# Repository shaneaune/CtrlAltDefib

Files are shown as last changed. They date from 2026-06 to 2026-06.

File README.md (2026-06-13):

# Ctrl+Alt+Defib

**Ctrl+Alt+Defib** is an ESP32-based power outage monitoring and automated shutdown system designed for Proxmox servers.

The system monitors utility power using a standard 5V USB power adapter. When utility power is lost, a configurable shutdown timer begins. If power is not restored before the timer expires, the Ctrl+Alt+Defib unit sends a secure shutdown request to a Proxmox shutdown service running in a lightweight Linux container. The shutdown service then performs a controlled shutdown of the Proxmox host to protect virtual machines, containers, and storage from unexpected power loss before the UPS batteries are depleted.

The ESP32 remains powered by the UPS during an outage, allowing it to continue monitoring power status. When utility power is restored, a separate configurable startup timer begins. Once the startup delay has expired, the Ctrl+Alt+Defib unit automatically sends a Wake-on-LAN packet to restart the Proxmox host.

The project is designed to be simple to deploy, inexpensive to build, and easy to configure. All settings are managed through a built-in web interface hosted directly on the Ctrl+Alt+Defib unit.

---

## Features

* Configurable shutdown delay timer
* Web-based configuration interface
* Secure token-protected shutdown requests
* Automated Proxmox shutdown-service container installer
* Wake-on-LAN support for automatic Proxmox host startup after power restoration
* Local event logging and status monitoring
* Open-source hardware and firmware
* Designed and tested for the ESP32-ETH02 Ethernet module

---

## Repository Structure

```text
.
├── docs
│   └── images
│       ├── Arduino-IDE-Settings.jpg
│       ├── Case-End.jpg
│       ├── Case-esp32.jpg
│       ├── Case-inside.jpg
│       ├── Hat-schematic.png
│       ├── Hookup-Diagram.png
│       ├── PCB-hat.jpg
│       ├── Webpage-config.jpg
│       ├── Webpage-log.jpg
│       └── Webpage-status.jpg
├── enclosure
│   └── stl
│       ├── CtrlAltDefib Case Lid.stl
│       ├── CtrlAltDefib Case.stl
│       └── Printing-Notes.md
├── firmware
│   └── CtrlAltDefib
│       └── CtrlAltDefib.ino
├── hardware
│   └── CtrlAltDefib-HAT
│       ├── CtrlAltDefib-HAT-Gerbers.zip
│       ├── CtrlAltDefib-HAT-Schematic.pdf
│       └── README.md
├── LICENSE
├── README.md
└── shutdown-service
    └── install-shutdown-service.sh
```

---

## How It Works

1. The Ctrl+Alt+Defib unit is powered by the UPS so it remains operational during a power outage.
2. A standard 5V USB-C power adapter monitors the presence of utility power.
3. If utility power is lost, a configurable shutdown countdown begins.
4. If utility power returns before the timer expires, the shutdown countdown is cancelled.
5. If the timer expires, the Ctrl+Alt+Defib unit sends a secure shutdown request to the Proxmox shutdown service.
6. The shutdown service cleanly shuts down the Proxmox host.
7. When utility power is restored, a configurable startup countdown begins.
8. When the startup countdown expires, the Ctrl+Alt+Defib unit automatically sends a Wake-on-LAN packet to restart the Proxmox host.

<p align="center">
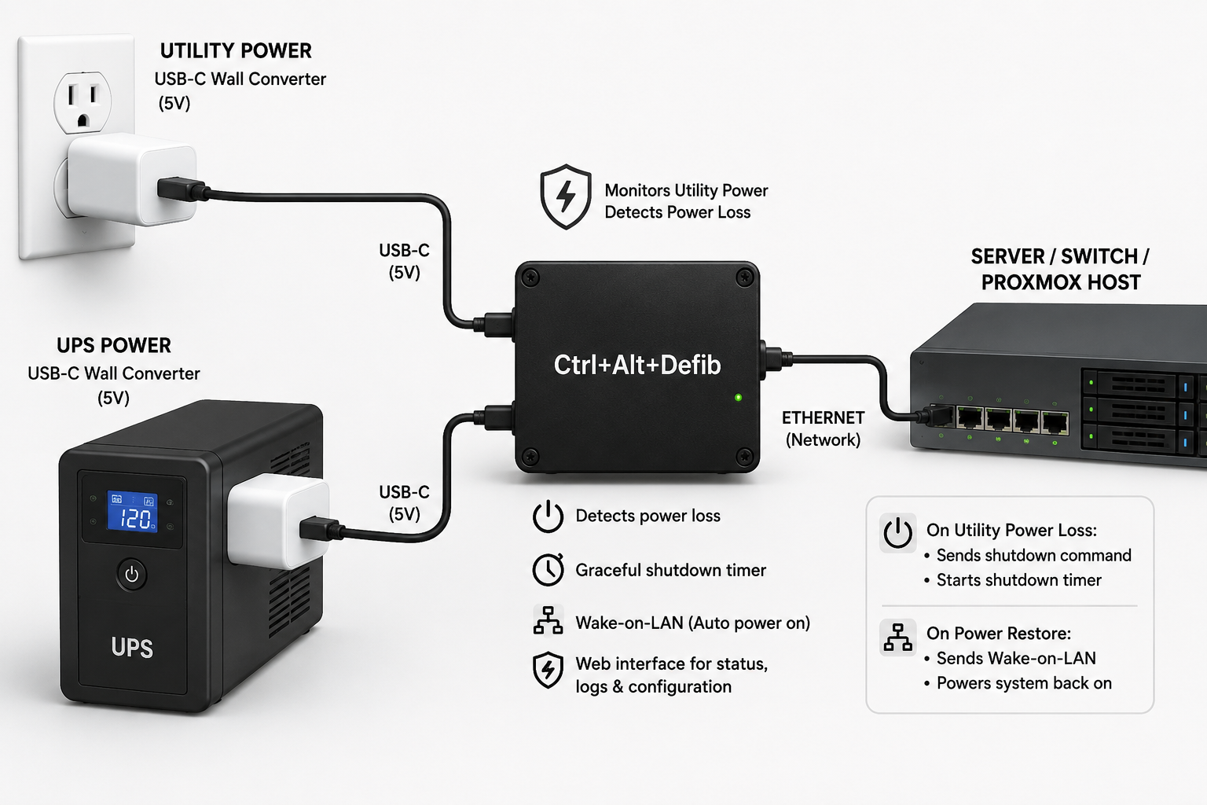
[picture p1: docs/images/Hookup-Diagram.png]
  
</p>

---

## Hardware

All hardware files required to build the project are located in the hardware/CtrlAltDefib-HAT directory.

The utility power sensing adapter must be connected to a non-UPS outlet. If it is connected to a UPS-backed outlet, the system will be unable to detect a utility power failure.

The Ctrl+Alt+Defib unit must remain powered during a utility power outage. This is typically accomplished using a UPS, but a suitable USB battery pack may also be used.

Network connectivity between the Ctrl+Alt+Defib unit and the Proxmox host must remain available during a power outage. If the Ctrl+Alt+Defib unit communicates through a network switch, the switch should also remain powered until the shutdown process is complete.

Failure to maintain power to the Ctrl+Alt+Defib unit or the network path will prevent the shutdown request from reaching the Proxmox host. 

---

## Assembled Unit

<p align="center">
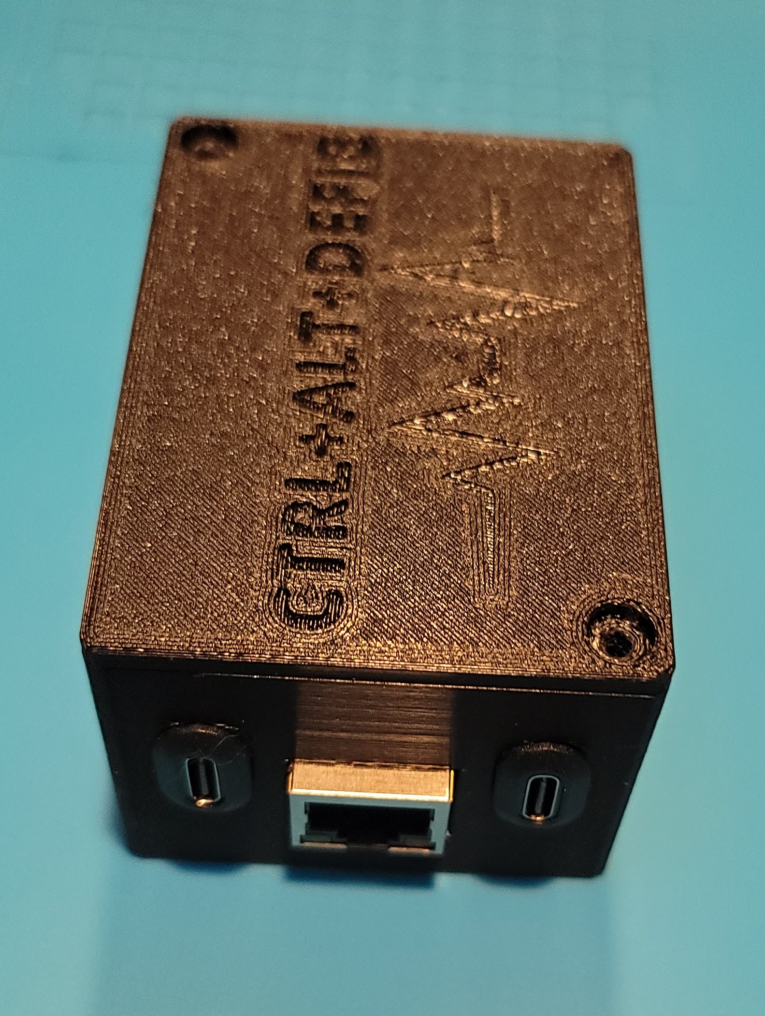
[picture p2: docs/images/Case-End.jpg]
  
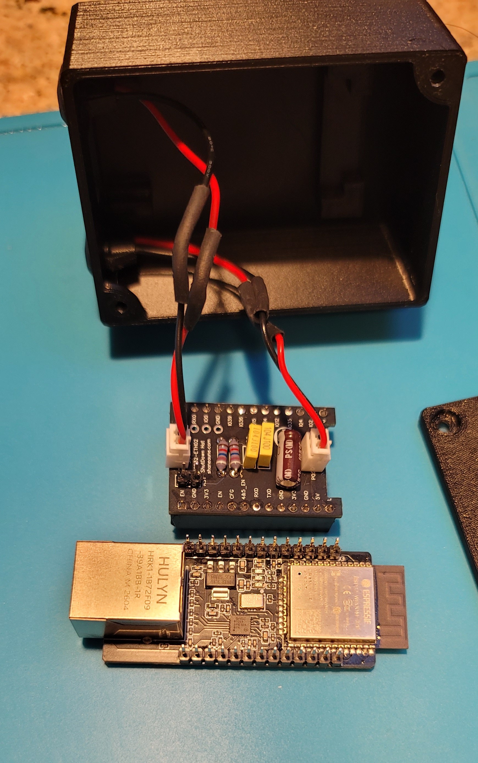
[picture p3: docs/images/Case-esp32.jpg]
  
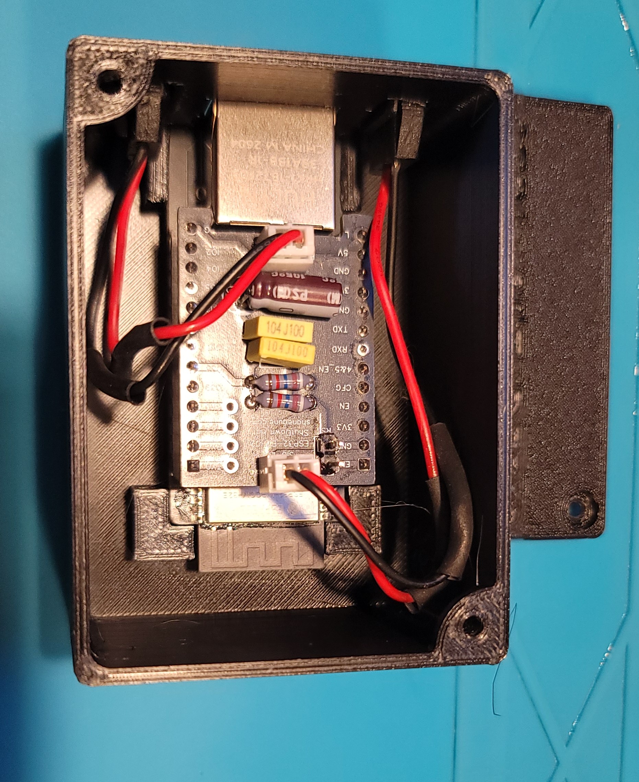
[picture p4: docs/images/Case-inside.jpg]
  
</p>

---

### Included Files

* Bill of Materials (BOM)
* PCB design files
* Schematic files

Refer to the hardware README for the complete bill of materials, sourcing information, and assembly notes.

The 3D printable enclosure files are located in the `enclosure` directory.

### Programming the ESP32-ETH02

The ESP32-ETH02 does not include a built-in USB programming interface.

To upload firmware, you will need one of the following:

* An ESP32-ETH02 programming adapter board
* A USB-to-Serial adapter with access to the required programming pins

The easiest option is to use one of the ESP32-ETH02 programming adapter boards available from Amazon, AliExpress, and other suppliers. These adapter boards typically provide:

* USB-C connection
* USB-to-Serial interface
* BOOT button
* RESET button
* Power regulation

These adapters allow the ESP32-ETH02 to be programmed directly from the Arduino IDE over USB without additional wiring.

---

## Firmware Installation

The firmware has been developed and tested on the ESP32-ETH02 Ethernet module using:

| Component | Version |
|---|---|
| Arduino IDE | 2.3.10 |
| ESP32 Board Package (Espressif Systems) | 3.3.10 |

Other LAN8720-based ESP32 Ethernet boards may work, but they have not been tested with this project and are not currently supported.

Open the `CtrlAltDefib.ino` sketch located in:

```text
firmware/CtrlAltDefib/
```

and upload it to your ESP32-ETH02 using the Arduino IDE.

### Install ESP32 Board Support

Before compiling the firmware, install the ESP32 board package using the Arduino IDE Board Manager.

1. Open **Tools → Board → Boards Manager**.
2. Search for:

ESP32

3. Install the **ESP32** package published by **Espressif Systems**.

The firmware was developed and tested using version **3.3.10** of the ESP32 board package.

After installation, select:

Tools → Board → ESP32 Arduino → ESP32 Dev Module

and configure the settings shown below.

### Arduino IDE Settings

The firmware was developed and tested using the following Arduino IDE settings:

| Setting | Value |
| --- | --- |
| Board | ESP32 Dev Module |
| CPU Frequency | 240MHz (WiFi/BT) |
| Core Debug Level | Info |
| Erase All Flash Before Sketch Upload | Disabled |
| Events Run On | Core 1 |
| Flash Frequency | 40MHz |
| Flash Mode | DIO |
| Flash Size | 4MB (32Mb) |
| JTAG Adapter | Disabled |
| Arduino Runs On | Core 1 |
| Partition Scheme | Default 4MB with spiffs (1.2MB APP/1.5MB SPIFFS) |
| PSRAM | Disabled |
| Upload Speed | 115200 |
| Zigbee Mode | Disabled |

<p align="left">
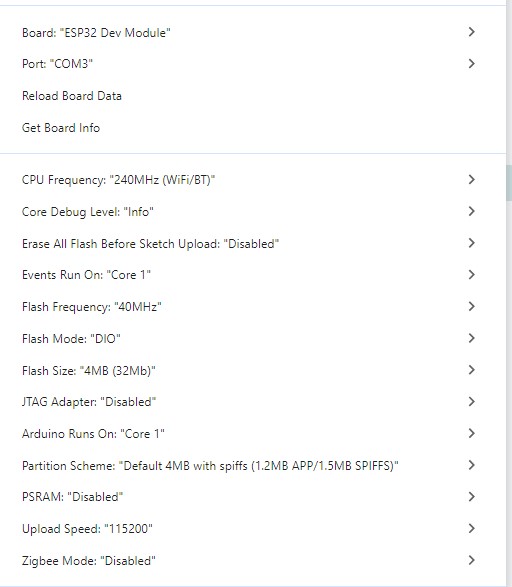
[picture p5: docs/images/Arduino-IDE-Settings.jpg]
  
</p>

---

### Configure Web Interface Credentials

Before compiling and uploading the firmware, edit the following lines in `CtrlAltDefib.ino`:

```cpp
constexpr const char *UI_USERNAME = "admin";
constexpr const char *UI_PASSWORD = "CHANGE-ME";
```

Change the password to a secure value before uploading the firmware.

Example:

```cpp
constexpr const char *UI_USERNAME = "admin";
constexpr const char *UI_PASSWORD = "MySecurePassword";
```

The web interface will use these credentials for authentication.

---

### Uploading the Firmware

1. Connect the ESP32-ETH02 to your programming adapter.
2. Connect the programming adapter to your computer using USB.
3. Open `firmware/CtrlAltDefib/CtrlAltDefib.ino` in the Arduino IDE.
4. Configure the username and password in the sketch before compiling.
5. Select the settings listed above.
6. Compile and upload the firmware.

### Required Libraries

Install any required libraries when prompted by the Arduino IDE.

After the firmware has been uploaded successfully, continue with the Proxmox Shutdown Service Setup section.

---

## Proxmox Shutdown Service Setup

The shutdown service runs inside a lightweight Debian LXC container and receives authenticated shutdown requests from the Ctrl+Alt+Defib unit .

The installer automatically creates and configures the container, installs all required software, generates SSH keys, and configures the shutdown service.

### Prerequisites

* Proxmox VE 8.x or newer
* Internet access from the Proxmox host
* A Debian 12 container template available in Proxmox

If a Debian 12 template is not already installed:

1. Open the Proxmox web interface.
2. Select the local storage.
3. Open **CT Templates**.
4. Download the latest **Debian 12 Standard** template.

### Download the Repository

Log in to the Proxmox host as root and clone the repository:

```bash
git clone https://github.com/shaneaune/CtrlAltDefib.git
cd CtrlAltDefib/shutdown-service
```

### Run the Installer

Make the installer executable and start it:

```bash
chmod +x install-shutdown-service.sh
./install-shutdown-service.sh
```

The installer will:

* Create the shutdown-service container
* Install required packages
* Generate the SSH shutdown key
* Install and start the shutdown service
* Display the Ctrl+Alt+Defib unit configuration settings
* Generate the authorized_keys entry required for Proxmox shutdown access

### Complete the Action Required Step

When the installer completes, it will display a line similar to:

```text
command="shutdown -h now",no-port-forwarding,no-agent-forwarding,no-pty ssh-ed25519 ...
```

Copy the entire line and add it to the Proxmox host's authorized_keys file:

```bash
nano /root/.ssh/authorized_keys
```

Paste the generated line onto a new line at the end of the file.

To save the file:

Ctrl+O
Enter

To exit Nano:

Ctrl+X

On the Proxmox host you can retrieve the generated line again at any time with:

```bash
pct exec <CTID> -- cat /root/proxmox_authorized_key.txt
```

---

### Record the  Ctrl+Alt+Defib Config Settings

The installer will display:

* Shutdown Service IP
* Shutdown Service Port
* Shutdown Token

These values will be required when configuring the Ctrl+Alt+Defib settings in the web interface.

---

## First Shutdown Test Preparation

The first time the shutdown-service container connects to the Proxmox host, SSH will prompt to verify the Proxmox host key.

Before performing the first shutdown test:

1. Open a console to the shutdown-service container.

2. Run:

pct enter <CTID>

3. Leave the console open during the first shutdown test.

When the shutdown timer expires, you will see a message similar to:

The authenticity of host '10.0.0.xxx' can't be established.
ED25519 key fingerprint is SHA256:xxxxxxxxxxxxxxxxxxxxxxxxxxxx.
Are you sure you want to continue connecting (yes/no/[fingerprint])?

Type:

yes

and press Enter.

The Proxmox host key will be saved and all future shutdowns will occur automatically without additional user interaction.

### First Shutdown Test

After the Ctrl+Alt+Defib unit has been configured, perform a shutdown test.

The first shutdown request will automatically save the Proxmox host SSH key within the shutdown-service container. Future shutdown requests will use the saved key automatically.

Verify that:

* The Ctrl+Alt+Defib unit detects utility power loss
* The shutdown timer expires as expected
* The Proxmox host shuts down cleanly
* Wake-on-LAN startup functions correctly after power restoration

> **Note:** During the first shutdown test only, you may be prompted to verify the Proxmox host SSH key as described in the previous section.

---

## Ctrl+Alt+Defib Web Configuration

After uploading the firmware and connecting the Ctrl+Alt+Defib unit to your network, the device will automatically obtain an IP address using DHCP.

Locate the assigned IP address using your router, DHCP server, or a network scanning tool and open the web interface in your browser:

```text
http://<ip-address>/
```

### Log In

Log in using the username and password configured in the firmware before uploading.

After logging in, the Status page will be displayed. Open the **Config** page to access the system settings.

### Configure the Shutdown Service

On the Configuration page, enter the values provided by the shutdown-service installer:

* Shutdown Service IP Address
* Shutdown Service Port
* Shutdown Token

### Configure Shutdown Settings

Set the desired shutdown delay. This determines how long the system will wait after utility power is lost before initiating a Proxmox shutdown.

### Configure Wake-on-LAN

Enter the MAC address of the Proxmox host and configure the desired startup delay.

When utility power is restored, the Ctrl+Alt+Defib unit will wait for the configured startup delay before sending the Wake-on-LAN packet.

### Save Settings

Save the configuration using the **Save Config** button. The Ctrl+Alt+Defib unit will begin monitoring utility power and managing shutdown and startup events using the configured settings.

<p align="center">
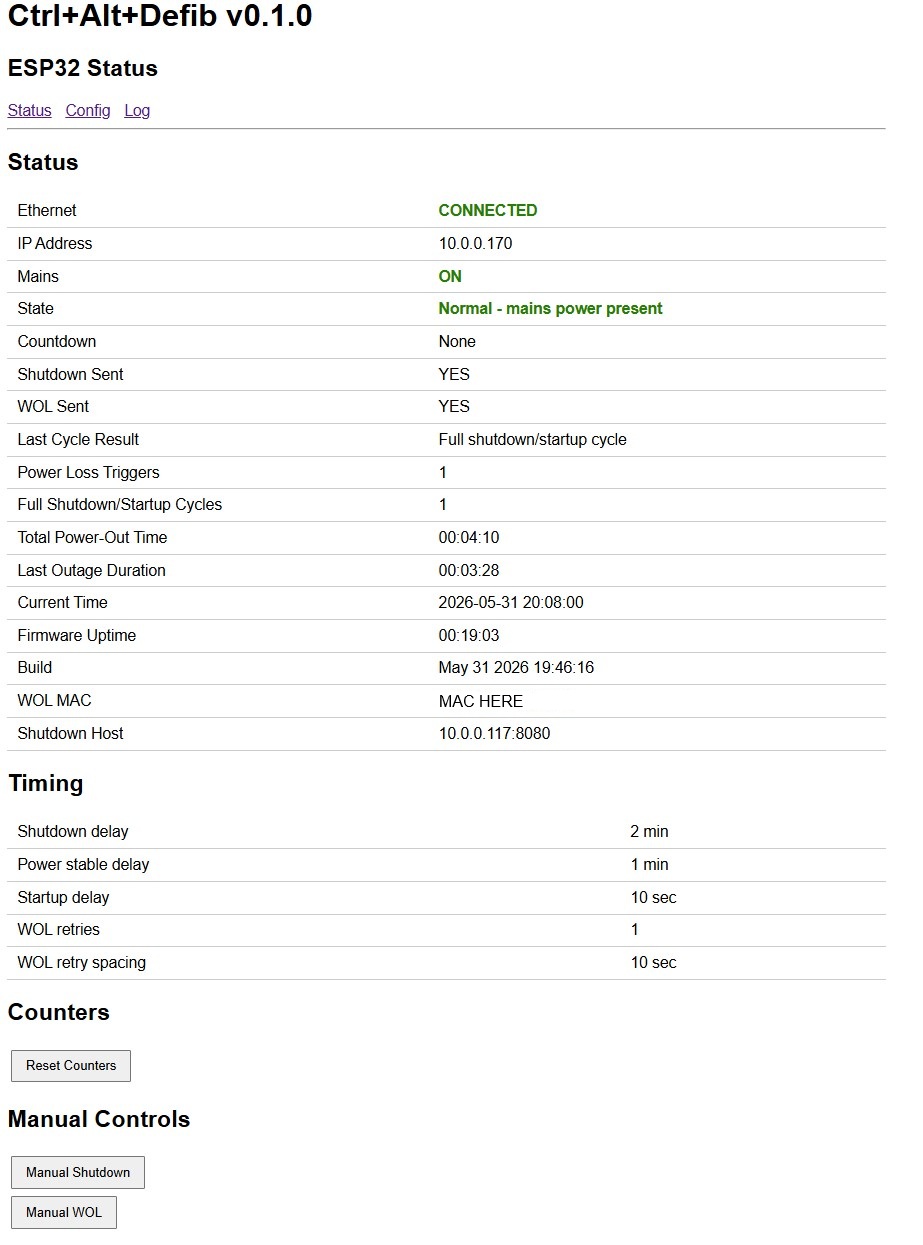
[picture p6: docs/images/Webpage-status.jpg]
  
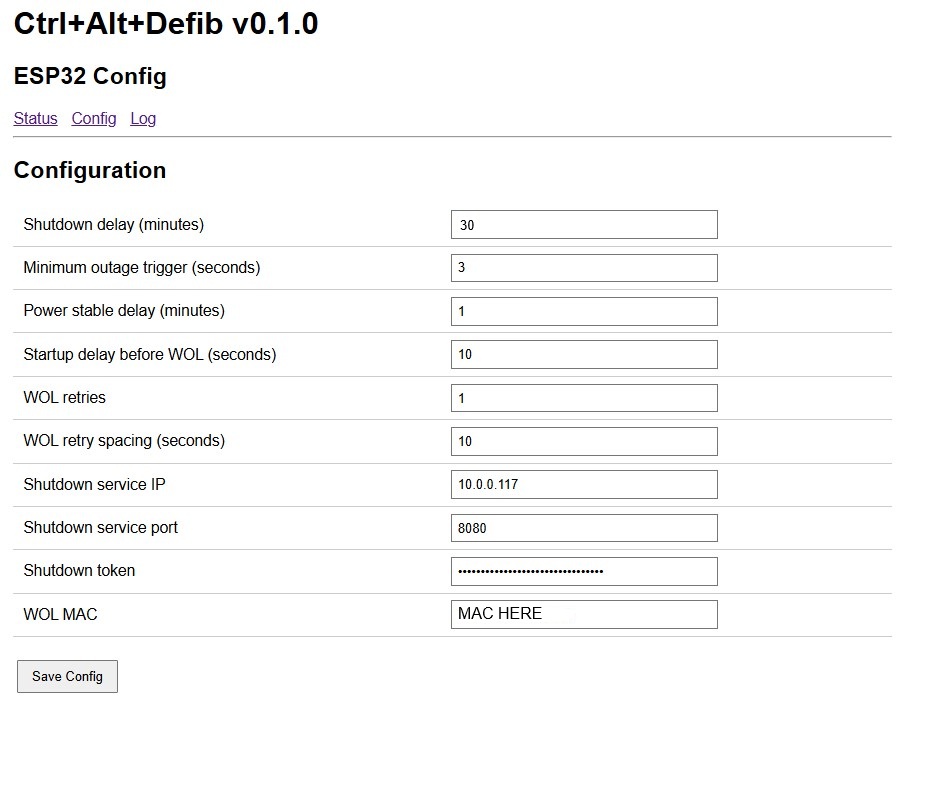
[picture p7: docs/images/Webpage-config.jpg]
  
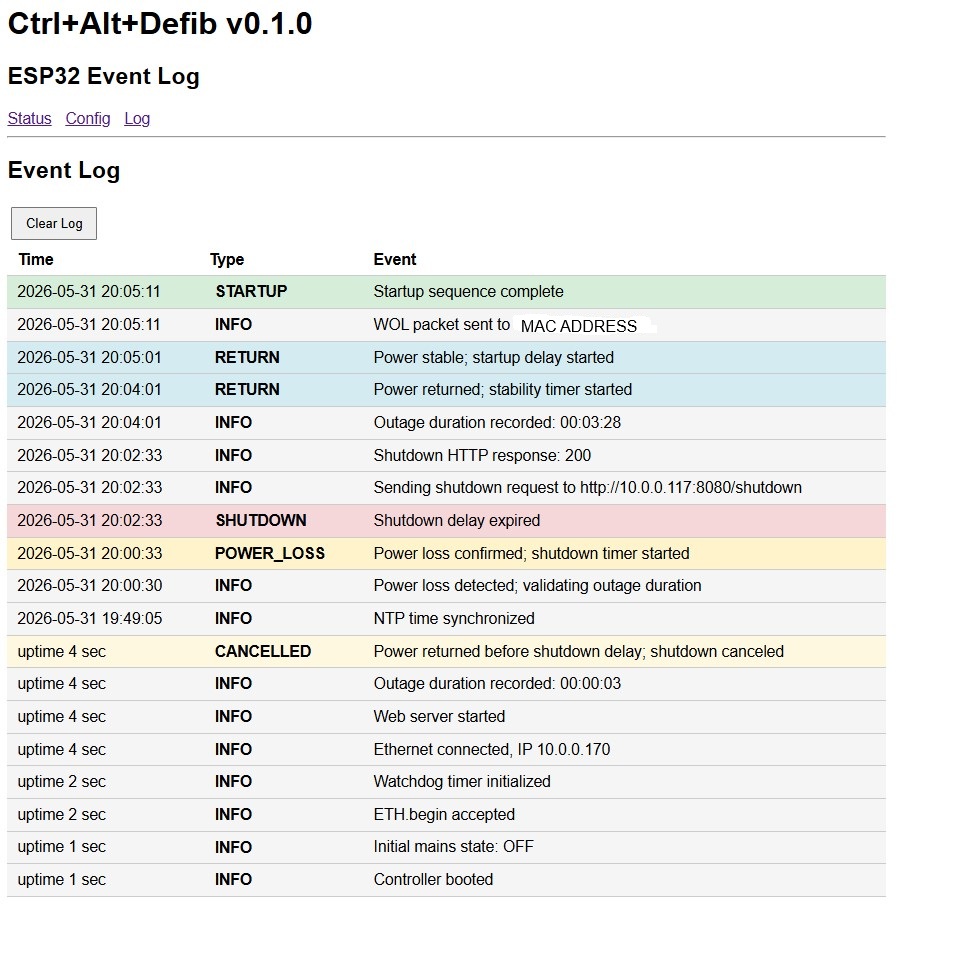
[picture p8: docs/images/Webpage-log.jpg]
  
</p>

---

## First Shutdown Test

Before relying on Ctrl+Alt+Defib to protect your Proxmox host, perform a complete functional test.

### Verify Power Detection

1. Ensure the Ctrl+Alt+Defib unit is powered from a UPS-backed outlet.
2. Ensure the utility power sensing adapter is connected to a non-UPS outlet.
3. Open the Ctrl+Alt+Defib Status page.
4. Verify that utility power is reported as present.

### Verify Shutdown Operation

1. Temporarily disconnect the utility power sensing adapter.
2. Verify that the shutdown countdown begins.
3. Allow the countdown to expire.
4. Confirm that the Proxmox host shuts down cleanly.

### Verify Startup Operation

1. Restore utility power.
2. Verify that the startup countdown begins.
3. Allow the startup delay to expire.
4. Confirm that a Wake-on-LAN packet is sent.
5. Verify that the Proxmox host powers on successfully.

### Verify System Status

After the test is complete, confirm that:

* Utility power status is reported correctly.
* Shutdown countdown operates correctly.
* Startup countdown operates correctly.
* The Proxmox host shuts down cleanly.
* Wake-on-LAN startup functions correctly.
* Event logs show the expected activity.

Once these checks have been completed successfully, the system is ready for normal operation.
---

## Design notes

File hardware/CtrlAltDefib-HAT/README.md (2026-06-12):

# Ctrl+Alt+Defib Bill of Materials

## Hardware

| Qty | Item | Notes |
| --- | --- | --- |
| 1 | ESP32-ETH02 | Purchased from AliExpress |
| 1 | Ctrl+Alt+Defib Hat PCB | Manufactured by JLCPCB, Gerbers provided. |
| 1 | 3D Printed Case | STL files provided in the enclosure directory |
| 1 | 3D Printed Lid | STL files provided in the enclosure directory |
| 2 | 5V USB Wall Adapter with USB-C Cable | One powers the ESP32 from the UPS, one monitors utility power |
| 2 | USB-C to 2-Wire Power Cable | Available from Amazon and other suppliers |
| 2 | JST PH 2.0mm Male Plug | Typically supplied with matching female connectors |
| 1 | ESP32-ETH02 Programming Adapter | Required for firmware uploads |

### Notes

The JST connectors are optional. The 5V and signal connections may be soldered directly to the PCB if preferred.

The Ctrl+Alt+Defib Hat circuit is intentionally simple and can be assembled on perf board if a PCB is not available.

If there is sufficient interest, PCBs may be made available in the future.

---

## Ctrl+Alt+Defib Hat Components

| Reference | Description | Value / Part |
| --- | --- | --- |
| 5V-IN | Power Input Connector | JST PH 2.0mm Female |
| SIG-IN | Utility Power Sense Input | JST PH 2.0mm Female |
| RST | ESP32 Reset Header | 2.54mm Pitch 1x2 Male Header |
| R1 | Voltage Divider Resistor  | 100KΩ 1/4W |
| R2 | Voltage Divider Resistor  | 100KΩ 1/4W |
| C1 | Filter Capacitor | 0.1µF Ceramic or Film |
| C2 | Power Supply Capacitor | 10µF 25V Electrolytic, 2mm Lead Spacing |
| C3 | Filter Capacitor | 0.1µF Ceramic or Film |
| U1 | ESP32 Connector | 2.54mm Pitch 1x13 Female Header |
| U2 | ESP32 Connector | 2.54mm Pitch 1x13 Female Header |

---

<p align="center">
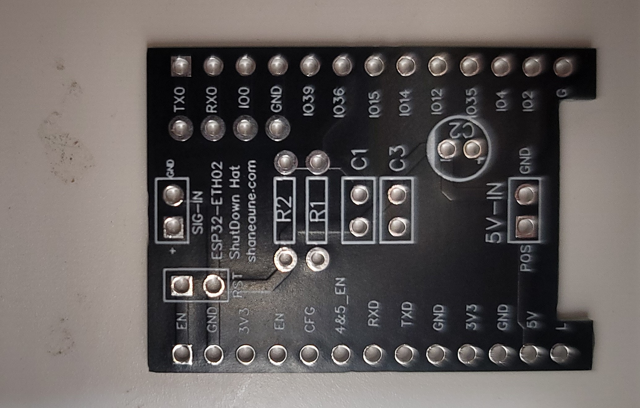
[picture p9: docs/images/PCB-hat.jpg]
  
</p>

---

## Suppliers

### WT32-ETH02

* AliExpress

### PCB

* JLCPCB

### Connectors and Cables

* Amazon
* AliExpress

### Passive Components

Most components are common through-hole parts available from:

* DigiKey
* Mouser
* Newark
* Amazon
* AliExpress

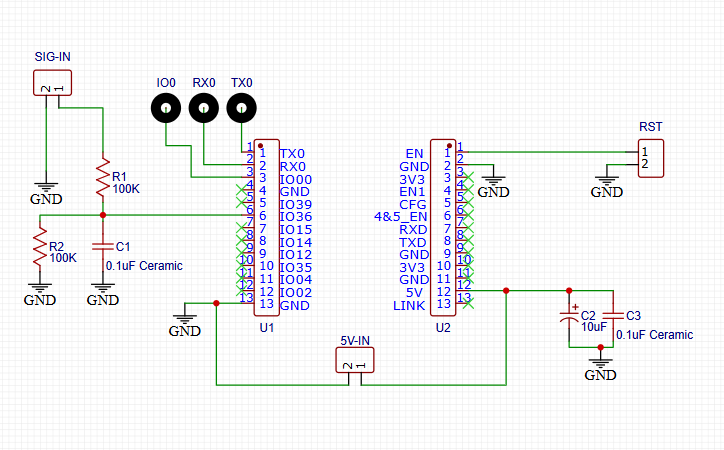
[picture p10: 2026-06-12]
docs/images/Hat-schematic.png

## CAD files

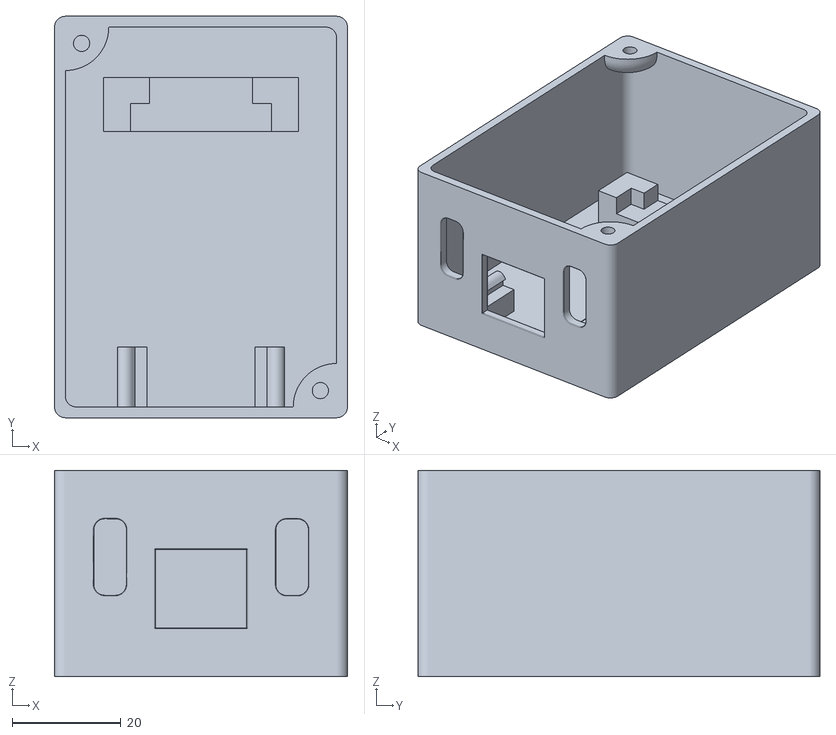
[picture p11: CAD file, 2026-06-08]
enclosure/stl/CtrlAltDefib Case.stl
54.0 x 74.0 x 38.0

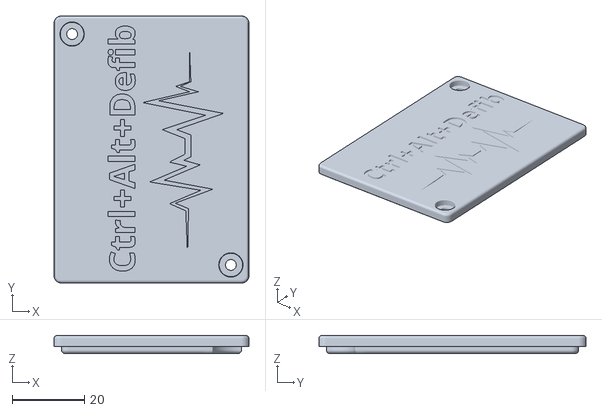
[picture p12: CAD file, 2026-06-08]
enclosure/stl/CtrlAltDefib Case Lid.stl
54.0 x 74.0 x 5.00

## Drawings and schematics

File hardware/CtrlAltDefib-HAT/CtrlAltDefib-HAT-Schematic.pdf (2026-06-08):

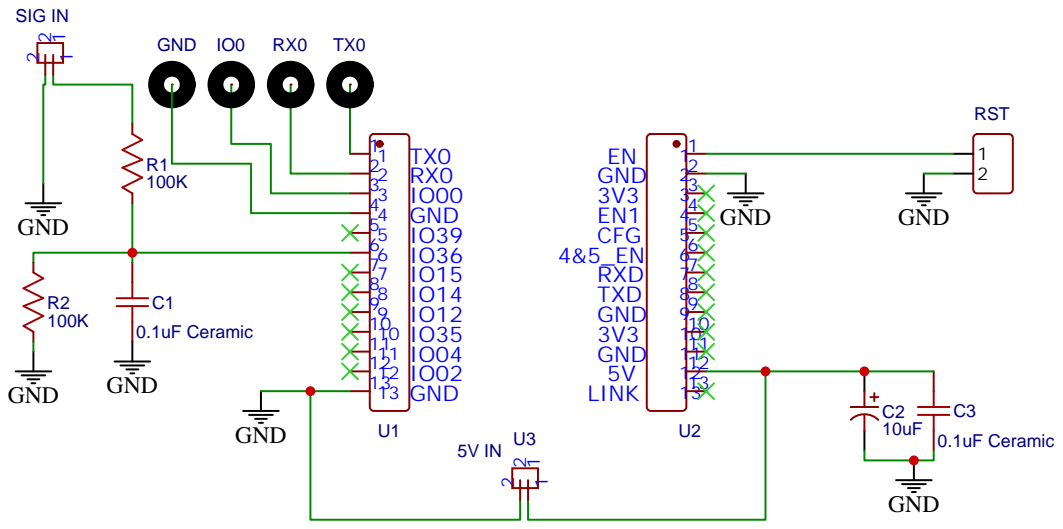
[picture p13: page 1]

Drawn By: Shane Aune

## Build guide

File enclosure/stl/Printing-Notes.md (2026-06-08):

# Ctrl+Alt+Defib Enclosure Printing Notes

The enclosure was designed and tested using PETG.

Recommended settings:

* Layer Height: 0.20 mm
* Nozzle Diameter: 0.40 mm
* Wall Loops: 3
* Infill: 15-20%
* Supports: I used tree supports on the top edges of the RJ45 and USB holes on the front of the case. For the lid you can use supports as well and it will print 4 little discs to support the screw hole insets.  

Printing Orientation:

## Case

Print the base with the bottom surface on the build plate.

## Lid

Print the lid with the outside top surface with the lettering on the build plate. This produces a smooth outer surface and provides the best appearance for the embossed or recessed logo.

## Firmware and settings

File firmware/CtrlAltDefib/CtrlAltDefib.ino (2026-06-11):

/*
  Ctrl+Alt+Defib - ESP32 Ethernet UPS Server Controller
  
  Programmed by Shane Aune - shaneaune.com
  Github: https://github.com/shaneaune

  Purpose:
    Monitors a mains-present signal and coordinates a controlled
    shutdown/startup sequence for a target server.

  Hardware:
    - ESP32-ETH02 with LAN8720 Ethernet PHY
    - GPIO36 reads a mains-present signal
    - The external sensing circuit must already level-shift/isolate
      the source signal to a safe ESP32 voltage

  Power-loss behavior:
    1. Detect loss of mains
    2. Ignore brief glitches using input debounce and outage validation
    3. After a confirmed outage, wait shutdownDelaySec
    4. Send an HTTP shutdown request to the target service
    5. When mains returns and remains stable, wait startupDelaySec
    6. Send Wake-on-LAN packets to restart the target server

  Design notes:
    - Main control flow is millis()-driven and mostly non-blocking
    - Ethernet is required for HTTP shutdown and Wake-on-LAN actions
    - Settings and outage counters persist in Preferences (NVS)
    - A watchdog timer is enabled to recover from unexpected stalls
*/

#include <Arduino.h>

#define ETH_PHY_TYPE ETH_PHY_LAN8720
#define ETH_PHY_ADDR 1
#define ETH_PHY_MDC 23
#define ETH_PHY_MDIO 18
#define ETH_PHY_POWER 16
#define ETH_CLK_MODE ETH_CLOCK_GPIO0_IN

#include <ETH.h>
#include <HTTPClient.h>
#include <Preferences.h>
#include <WebServer.h>
#include <WiFiUdp.h>
#include <esp_task_wdt.h>
#include <time.h>

// GPIO36 is input-only on ESP32 and is used only for mains sensing.
// The external circuit must convert the source signal to a safe logic level.
constexpr uint8_t MAINS_PIN = 36;

constexpr const char *PROJECT_NAME = "Ctrl+Alt+Defib";
constexpr const char *FIRMWARE_VERSION = "v0.1.0";

constexpr const char *BUILD_DATE = __DATE__;
constexpr const char *BUILD_TIME = __TIME__;

constexpr const char *UI_USERNAME = "admin";
constexpr const char *UI_PASSWORD = "CHANGE-ME";

// Log type labels are centralized to avoid typo-prone string literals.
constexpr const char *LOG_INFO = "INFO";
constexpr const char *LOG_POWER_LOSS = "POWER_LOSS";
constexpr const char *LOG_CANCELLED = "CANCELLED";
constexpr const char *LOG_SHUTDOWN = "SHUTDOWN";
constexpr const char *LOG_RETURN = "RETURN";
constexpr const char *LOG_STARTUP = "STARTUP";
constexpr const char *LOG_ERROR = "ERROR";

constexpr unsigned long MAINS_DEBOUNCE_MS = 1000;
constexpr int LOG_SIZE = 50;
constexpr uint32_t WDT_TIMEOUT_MS = 30000;
constexpr unsigned long MILLIS_PER_SEC = 1000UL;

WebServer server(80);
Preferences prefs;

bool ethConnected = false;
bool mainsPresent = false;
bool shutdownSent = false;
bool wolSent = false;
bool timeSynced = false;
bool webServerStarted = false;

// lastRawMainsReading tracks the immediate GPIO level.
// mainsPresent is the debounced signal consumed by the state machine.
bool lastRawMainsReading = false;
unsigned long rawMainsChangedMs = 0;

uint32_t powerLossTriggerCount = 0;
uint32_t fullCycleCount = 0;
uint64_t totalPowerOutSec = 0;
uint32_t lastOutageSec = 0;
String lastCycleResult = "None";

unsigned long outageStartMs = 0;
unsigned long outageDetectStartMs = 0;
unsigned long powerReturnStartMs = 0;
unsigned long startupDelayStartMs = 0;
unsigned long lastWolMs = 0;
uint8_t wolRetryCounter = 0;

// State machine overview:
// - POWER_ON_IDLE: normal operation, mains present
// - POWER_OUTAGE_DETECTED: outage seen, waiting to confirm it is real
// - POWER_FAIL_PENDING: outage confirmed, shutdown countdown running
// - SHUTDOWN_SENT: shutdown already requested, waiting for mains return
// - POWER_RETURN_PENDING: mains returned, checking that it remains stable
// - WOL_PENDING: stable power confirmed, waiting to send WOL sequence
enum SystemState {
  POWER_ON_IDLE,
  POWER_OUTAGE_DETECTED,
  POWER_FAIL_PENDING,
  SHUTDOWN_SENT,
  POWER_RETURN_PENDING,
  WOL_PENDING
};

SystemState state = POWER_ON_IDLE;

struct Config {
  uint32_t shutdownDelaySec = 300;
  uint32_t minOutageTriggerSec = 3;
  uint32_t powerStableDelaySec = 120;
  uint32_t startupDelaySec = 120;
  uint8_t wolRetries = 3;
  uint32_t wolRetrySpacingSec = 10;

  char shutdownHost[32] = "10.0.0.117";
  uint16_t shutdownPort = 8080;
  char shutdownToken[96] = "8f3c91a2b7d44e1c9a5f2b8d7c6e4a11";

  uint8_t wolMac[6] = { 0xC4, 0x34, 0x6B, 0x7E, 0x16, 0x8E };
};

Config cfg;

struct LogEntry {
  String type;
  String time;
  String message;
};

LogEntry eventLog[LOG_SIZE];
int logIndex = 0;
int logCount = 0;

unsigned long secondsToMs(uint32_t seconds) {
  return static_cast<unsigned long>(seconds) * MILLIS_PER_SEC;
}

String macToString(const uint8_t mac[6]) {
  char buf[18];
  snprintf(
    buf,
    sizeof(buf),
    "%02X:%02X:%02X:%02X:%02X:%02X",
    mac[0],
    mac[1],
    mac[2],
    mac[3],
    mac[4],
    mac[5]);
  return String(buf);
}

bool parseMac(const String &s, uint8_t mac[6]) {
  int values[6];
  if (sscanf(
        s.c_str(),
        "%x:%x:%x:%x:%x:%x",
        &values[0],
        &values[1],
        &values[2],
        &values[3],
        &values[4],
        &values[5])
      != 6) {
    return false;
  }

  for (int i = 0; i < 6; i++) {
    if (values[i] < 0 || values[i] > 255) {
      return false;
    }
    mac[i] = static_cast<uint8_t>(values[i]);
  }

  return true;
}

String nowString() {
  struct tm timeinfo;
  if (getLocalTime(&timeinfo, 50)) {
    char buf[24];
    strftime(buf, sizeof(buf), "%Y-%m-%d %H:%M:%S", &timeinfo);
    return String(buf);
  }

  const unsigned long seconds = millis() / MILLIS_PER_SEC;
  char buf[24];
  snprintf(buf, sizeof(buf), "uptime %lu sec", seconds);
  return String(buf);
}

// Appends a log entry to the ring buffer and mirrors it to Serial.
// The ring buffer keeps the newest LOG_SIZE events only.
void addLog(const String &type, const String &msg) {
  eventLog[logIndex].type = type;
  eventLog[logIndex].time = nowString();
  eventLog[logIndex].message = msg;

  const String line = eventLog[logIndex].time + " [" + type + "] " + msg;

  logIndex = (logIndex + 1) % LOG_SIZE;
  if (logCount < LOG_SIZE) {
    logCount++;
  }

  Serial.println(line);
}

void addLog(const String &msg) {
  addLog(LOG_INFO, msg);
}

String formatDuration(uint64_t totalSec) {
  const uint64_t days = totalSec / 86400;
  const uint8_t hours = (totalSec % 86400) / 3600;
  const uint8_t minutes = (totalSec % 3600) / 60;
  const uint8_t seconds = totalSec % 60;

  char buf[32];

  if (days > 0) {
    snprintf(
      buf,
      sizeof(buf),
      "%llu d %02u:%02u:%02u",
      days,
      hours,
      minutes,
      seconds);
  } else {
    snprintf(buf, sizeof(buf), "%02u:%02u:%02u", hours, minutes, seconds);
  }

  return String(buf);
}

String formatCountdown(unsigned long remainingMs) {
  const uint32_t totalSec = remainingMs / MILLIS_PER_SEC;
  const uint8_t minutes = totalSec / 60;
  const uint8_t seconds = totalSec % 60;

  char buf[16];
  snprintf(buf, sizeof(buf), "%02u:%02u", minutes, seconds);
  return String(buf);
}

// Returns the user-facing countdown/status text for the current state.
String currentCountdownText() {
  const unsigned long now = millis();

  if (state == POWER_OUTAGE_DETECTED) {
    const unsigned long elapsed = now - outageDetectStartMs;
    const unsigned long total = secondsToMs(cfg.minOutageTriggerSec);

    if (elapsed >= total) {
      return "Outage confirmed";
    }

    return "Validating outage: " + formatCountdown(total - elapsed);
  }

  if (state == POWER_FAIL_PENDING) {
    const unsigned long elapsed = now - outageStartMs;
    const unsigned long total = secondsToMs(cfg.shutdownDelaySec);

    if (elapsed >= total) {
      return "Shutdown pending";
    }

    return "Shutdown in " + formatCountdown(total - elapsed);
  }

  if (state == POWER_RETURN_PENDING) {
    const unsigned long elapsed = now - powerReturnStartMs;
    const unsigned long total = secondsToMs(cfg.powerStableDelaySec);

    if (elapsed >= total) {
      return "Startup delay pending";
    }

    return "Power stable check: " + formatCountdown(total - elapsed);
  }

  if (state == WOL_PENDING) {
    const unsigned long elapsed = now - startupDelayStartMs;
    const unsigned long total = secondsToMs(cfg.startupDelaySec);

    if (elapsed >= total) {
      return "WOL sending";
    }

    return "WOL in " + formatCountdown(total - elapsed);
  }

  return "None";
}

String friendlyStateName(SystemState s) {
  switch (s) {
    case POWER_ON_IDLE:
      return "<span style='color:green;font-weight:bold;'>Normal - mains power present</span>";

    case POWER_OUTAGE_DETECTED:
      return "<span style='color:orange;font-weight:bold;'>Power outage detected - validating outage duration</span>";

    case POWER_FAIL_PENDING:
      return "<span style='color:red;font-weight:bold;'>Power outage detected - shutdown countdown running</span>";

    case SHUTDOWN_SENT:
      return "<span style='color:darkred;font-weight:bold;'>Shutdown command sent - waiting for power return</span>";

    case POWER_RETURN_PENDING:
      return "<span style='color:orange;font-weight:bold;'>Power restored - waiting for stable power</span>";

    case WOL_PENDING:
      return "<span style='color:blue;font-weight:bold;'>Power stable - waiting to send WOL</span>";

    default:
      return "<span style='color:gray;'>Unknown state</span>";
  }
}

// Applies the same effective limits as the original code, but keeps
// the policy in one place instead of repeating it in request handlers.
void validateConfigValues() {
  if (cfg.shutdownDelaySec < 60) {
    cfg.shutdownDelaySec = 60;
  }

  if (cfg.powerStableDelaySec < 60) {
    cfg.powerStableDelaySec = 60;
  }

  if (cfg.minOutageTriggerSec < 1) {
    cfg.minOutageTriggerSec = 1;
  }

  if (cfg.minOutageTriggerSec > 60) {
    cfg.minOutageTriggerSec = 60;
  }

  if (cfg.startupDelaySec < 1) {
    cfg.startupDelaySec = 1;
  }

  if (cfg.wolRetries < 1) {
    cfg.wolRetries = 1;
  }

  if (cfg.wolRetrySpacingSec < 1) {
    cfg.wolRetrySpacingSec = 1;
  }
}

// Loads both user settings and long-lived outage statistics from NVS.
// Defaults come from the in-memory cfg struct if a key is missing.
void loadConfig() {
  prefs.begin("config", true);

  cfg.shutdownDelaySec = prefs.getUInt("shutdown", cfg.shutdownDelaySec);
  cfg.minOutageTriggerSec = prefs.getUInt("minTrigger", cfg.minOutageTriggerSec);
  cfg.powerStableDelaySec = prefs.getUInt("stable", cfg.powerStableDelaySec);
  cfg.startupDelaySec = prefs.getUInt("startup", cfg.startupDelaySec);
  cfg.wolRetries = prefs.getUChar("wolRetries", cfg.wolRetries);
  cfg.wolRetrySpacingSec = prefs.getUInt("wolSpacing", cfg.wolRetrySpacingSec);
  cfg.shutdownPort = prefs.getUShort("port", cfg.shutdownPort);

  powerLossTriggerCount = prefs.getUInt("lossCount", 0);
  fullCycleCount = prefs.getUInt("cycleCount", 0);
  totalPowerOutSec = prefs.getULong64("totalOut", 0);
  lastOutageSec = prefs.getUInt("lastOut", 0);
  lastCycleResult = prefs.getString("lastCycle", "None");

  const String host = prefs.getString("host", cfg.shutdownHost);
  const String token = prefs.getString("token", cfg.shutdownToken);
  const String mac = prefs.getString("mac", macToString(cfg.wolMac));

  host.toCharArray(cfg.shutdownHost, sizeof(cfg.shutdownHost));
  token.toCharArray(cfg.shutdownToken, sizeof(cfg.shutdownToken));
  parseMac(mac, cfg.wolMac);

  prefs.end();

  validateConfigValues();
}

// Persists runtime configuration and outage counters so the controller
// can recover its settings and historical stats after reboot.
void saveConfig() {
  validateConfigValues();

  prefs.begin("config", false);

  prefs.putUInt("shutdown", cfg.shutdownDelaySec);
  prefs.putUInt("minTrigger", cfg.minOutageTriggerSec);
  prefs.putUInt("stable", cfg.powerStableDelaySec);
  prefs.putUInt("startup", cfg.startupDelaySec);
  prefs.putUChar("wolRetries", cfg.wolRetries);
  prefs.putUInt("wolSpacing", cfg.wolRetrySpacingSec);
  prefs.putUShort("port", cfg.shutdownPort);
  prefs.putString("host", cfg.shutdownHost);
  prefs.putString("token", cfg.shutdownToken);
  prefs.putString("mac", macToString(cfg.wolMac));

  prefs.putUInt("lossCount", powerLossTriggerCount);
  prefs.putUInt("cycleCount", fullCycleCount);
  prefs.putULong64("totalOut", totalPowerOutSec);
  prefs.putUInt("lastOut", lastOutageSec);
  prefs.putString("lastCycle", lastCycleResult);

  prefs.end();
}

// Sends the shutdown request to the external shutdown-service container.
// If Ethernet is unavailable, the request is skipped and only logged.
void sendShutdownCommand() {
  if (!ethConnected) {
    addLog("Shutdown skipped: Ethernet disconnected");
    return;
  }

  HTTPClient http;
  const String url =
    String("http://") + cfg.shutdownHost + ":" + cfg.shutdownPort + "/shutdown";

  addLog("Sending shutdown request to " + url);

  http.begin(url);
  http.addHeader("Authorization", String("Bearer ") + cfg.shutdownToken);

  const int code = http.POST("");

  addLog("Shutdown HTTP response: " + String(code));

  http.end();
  shutdownSent = true;
}

// Builds and sends a standard Wake-on-LAN magic packet:
// 6 bytes of 0xFF followed by the target MAC repeated 16 times.
void sendOneWolPacket() {
  WiFiUDP udp;
  uint8_t packet[102];

  for (int i = 0; i < 6; i++) {
    packet[i] = 0xFF;
  }

  for (int i = 0; i < 16; i++) {
    memcpy(&packet[6 + i * 6], cfg.wolMac, 6);
  }

  udp.beginPacket("255.255.255.255", 9);
  udp.write(packet, sizeof(packet));
  udp.endPacket();

  addLog("WOL packet sent to " + macToString(cfg.wolMac));
}

// Resets the retry bookkeeping for the pending WOL sequence.
// Actual WOL packets are sent later by updateWolRetries().
void startWolSequence() {
  if (!ethConnected) {
    addLog("WOL skipped: Ethernet disconnected");
    return;
  }

  wolRetryCounter = 0;
  lastWolMs = 0;
  wolSent = false;
}

// Sends repeated WOL packets with spacing to improve wake reliability.
// The sequence completes after cfg.wolRetries packets have been sent.
void updateWolRetries() {
  if (state != WOL_PENDING || !ethConnected) {
    return;
  }

  const unsigned long now = millis();
  const unsigned long retrySpacingMs = secondsToMs(cfg.wolRetrySpacingSec);

  if (wolRetryCounter == 0 || now - lastWolMs >= retrySpacingMs) {
    sendOneWolPacket();
    wolRetryCounter++;
    lastWolMs = now;

    if (wolRetryCounter >= cfg.wolRetries) {
      wolSent = true;

      fullCycleCount++;
      lastCycleResult = "Full shutdown/startup cycle";
      saveConfig();

      addLog(LOG_STARTUP, "Startup sequence complete");

      state = POWER_ON_IDLE;
    }
  }
}

// Debounces the raw mains-present input before exposing it as mainsPresent.
// The state machine only consumes the debounced signal, not the raw GPIO.
void updateMainsInput() {
  const bool reading = digitalRead(MAINS_PIN) == HIGH;
  const unsigned long now = millis();

  if (reading != lastRawMainsReading) {
    lastRawMainsReading = reading;
    rawMainsChangedMs = now;
  }

  if (now - rawMainsChangedMs >= MAINS_DEBOUNCE_MS) {
    mainsPresent = reading;
  }
}

// Records outage length in whole seconds.
// Very short measured outages are rounded up to 1 second so they are not
// silently stored as zero-duration events.
void recordOutageDuration(unsigned long now) {
  const unsigned long outageMs = now - outageStartMs;

  lastOutageSec = outageMs / MILLIS_PER_SEC;
  if (outageMs > 0 && lastOutageSec == 0) {
    lastOutageSec = 1;
  }

  totalPowerOutSec += lastOutageSec;

  saveConfig();

  addLog(LOG_INFO, "Outage duration recorded: " + formatDuration(lastOutageSec));
}

// Drives the outage/shutdown/restart lifecycle.
// All waits are millis()-based so the controller remains responsive while
// serving HTTP and resetting the watchdog.
void updateStateMachine() {
  const unsigned long now = millis();

  switch (state) {
    case POWER_ON_IDLE:
      if (!mainsPresent) {
        outageDetectStartMs = now;

        // First loss indication seen; do not start shutdown timing yet.
        // Wait until the outage survives the validation window.
        addLog(LOG_INFO, "Power loss detected; validating outage duration");
        state = POWER_OUTAGE_DETECTED;
      }
      break;

    case POWER_OUTAGE_DETECTED:
      if (mainsPresent) {
        addLog(LOG_INFO, "Short power loss ignored");
        state = POWER_ON_IDLE;
      } else if (now - outageDetectStartMs >= secondsToMs(cfg.minOutageTriggerSec)) {
        outageStartMs = now;
        shutdownSent = false;
        wolSent = false;

        powerLossTriggerCount++;
        saveConfig();

        addLog(LOG_POWER_LOSS, "Power loss confirmed; shutdown timer started");
        state = POWER_FAIL_PENDING;
      }
      break;

    case POWER_FAIL_PENDING:
      if (mainsPresent) {
        recordOutageDuration(now);

        lastCycleResult = "Cancelled outage";
        saveConfig();

        addLog(
          LOG_CANCELLED,
          "Power returned before shutdown delay; shutdown canceled");
        state = POWER_ON_IDLE;
      } else if (now - outageStartMs >= secondsToMs(cfg.shutdownDelaySec)) {
        addLog(LOG_SHUTDOWN, "Shutdown delay expired");
        sendShutdownCommand();
        state = SHUTDOWN_SENT;
      }
      break;

    case SHUTDOWN_SENT:
      if (mainsPresent) {
        recordOutageDuration(now);

        powerReturnStartMs = now;
        addLog(LOG_RETURN, "Power returned; stability timer started");
        state = POWER_RETURN_PENDING;
      }
      break;

    case POWER_RETURN_PENDING:
      if (!mainsPresent) {
        addLog("Power dropped again during stability delay");
        state = SHUTDOWN_SENT;
      } else if (now - powerReturnStartMs >= secondsToMs(cfg.powerStableDelaySec)) {
        startupDelayStartMs = now;
        addLog(LOG_RETURN, "Power stable; startup delay started");
        state = WOL_PENDING;
        startWolSequence();
      }
      break;

    case WOL_PENDING:
      if (!mainsPresent) {
        addLog("Power dropped again before WOL complete");
        state = SHUTDOWN_SENT;
      } else if (now - startupDelayStartMs >= secondsToMs(cfg.startupDelaySec)) {
        updateWolRetries();
      }
      break;
  }
}

// Protects the web UI with HTTP Basic Auth.
bool requireAuth() {
  if (!server.authenticate(UI_USERNAME, UI_PASSWORD)) {
    server.requestAuthentication();
    return false;
  }

  return true;
}

// Shared HTML shell for the minimal built-in UI.
// Styling is inline to keep deployment self-contained on the ESP32.
String htmlHeader(const String &title) {
  String h;
  h += "<!doctype html><html><head>";
  h += "<title>" + title + "</title>";
  h += "<meta name='viewport' content='width=device-width,initial-scale=1'>";
  h += "<style>";
  h += "body{font-family:Arial;margin:24px;max-width:900px;}";
  h += "table{border-collapse:collapse;width:100%;margin-bottom:20px;}";
  h += "td,th{padding:7px 10px;border-bottom:1px solid #ccc;text-align:left;}";
  h += "input{padding:6px;width:260px;}";
  h += "button{padding:8px 14px;margin:4px;}";
  h += ".nav a{margin-right:14px;}";
  h += ".ok{color:green;font-weight:bold;}.bad{color:red;font-weight:bold;}";
  h += ".log-info{background:#f5f5f5;}";
  h += ".log-power-loss{background:#fff3cd;}";
  h += ".log-cancelled{background:#fff8e1;}";
  h += ".log-shutdown{background:#f8d7da;}";
  h += ".log-return{background:#d1ecf1;}";
  h += ".log-startup{background:#d4edda;}";
  h += ".log-error{background:#f5c6cb;font-weight:bold;}";
  h += ".badge{font-weight:bold;padding:2px 6px;border-radius:4px;}";
  h += "</style></head><body>";
  h += "<h1>" + String(PROJECT_NAME) + " " + String(FIRMWARE_VERSION) + "</h1>";
  h += "<h2>" + title + "</h2>";
  h += "<div class='nav'>";
  h += "<a href='/'>Status</a>";
  h += "<a href='/config'>Config</a>";
  h += "<a href='/log'>Log</a>";
  h += "</div><hr>";
  return h;
}

String htmlFooter() {
  return "</body></html>";
}
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
void loop() {
  updateMainsInput();
  updateStateMachine();

  if (ethConnected) {
    server.handleClient();
    checkTimeSyncStatus();
  }

  esp_task_wdt_reset();

  // Short pacing delay keeps CPU usage reasonable while preserving
  // responsive outage handling and UI servicing.
  delay(50);
}

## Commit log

2026-06-11 Update CtrlAltDefib.ino
    Removed password from code, replaced with CHANGE-ME
    [CtrlAltDefib.ino]
2026-06-11 Delete hardware/CtrlAltDefib-HAT/CtrlAltDefib-HAT-BOM.csv
    deleted old bom
    [CtrlAltDefib-HAT-BOM.csv]
2026-06-12 Update README.md
    added pcb pic to hardware readme
2026-06-12 Update README.md
    added instructions for board type
2026-06-12 Update README.md
    Moved a couple sections around for correct work flow
